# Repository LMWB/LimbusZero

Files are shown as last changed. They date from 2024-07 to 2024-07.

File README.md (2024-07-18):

# LimbusZero
Custom Microcontroller Board based on STM32C0-Series

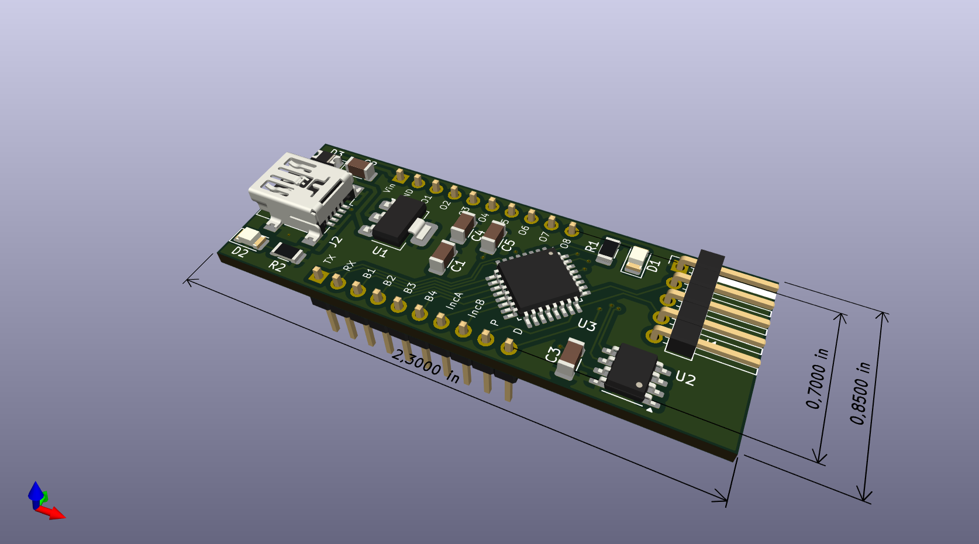
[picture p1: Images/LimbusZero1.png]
front

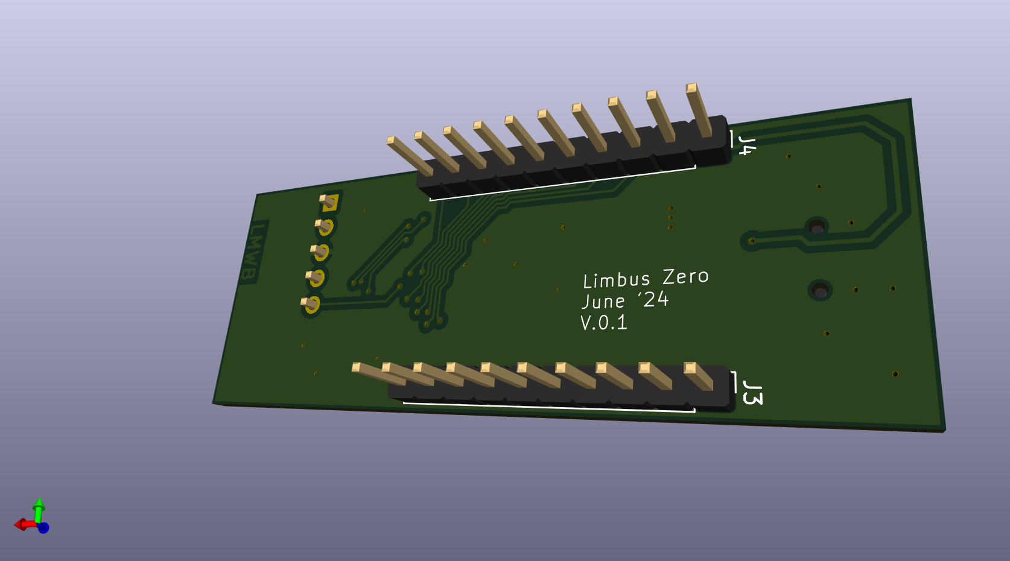
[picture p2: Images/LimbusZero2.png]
back

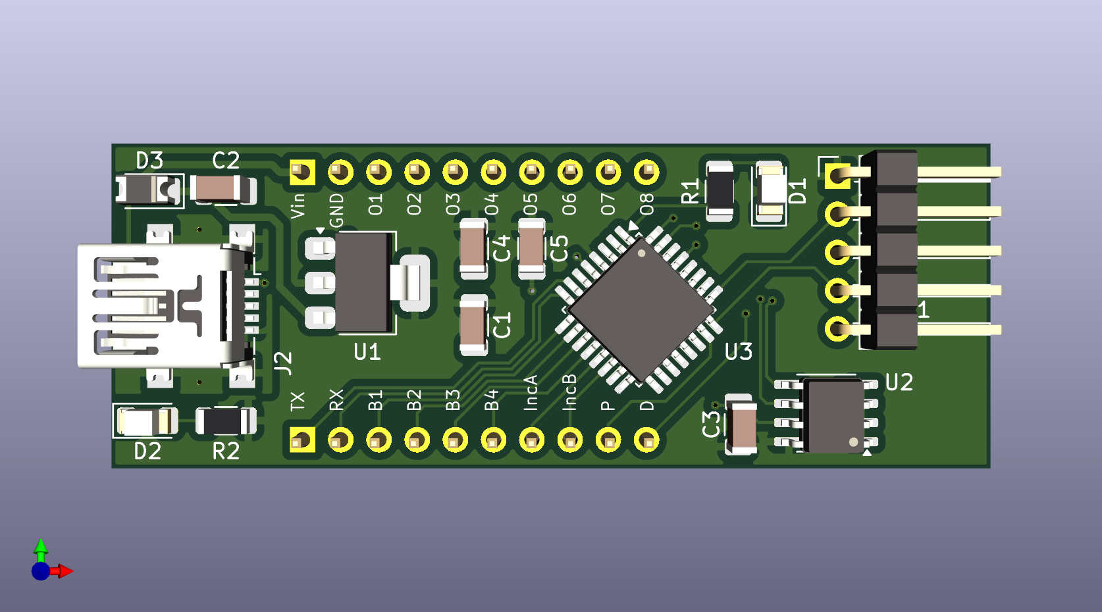
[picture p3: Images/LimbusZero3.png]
top

schematics

# Features
- STM32C031K6T6 Microcontroller
- ST M24C01 I2C EEPROM
- no crystal oscillator since this board uses STM32 build in 48MHz HSI48RC clock generator
    - accuracy needs to be discussed but since software is working fine I guess there will be no dramatic issus 
- Power indicator LED
- USB mini as power supply NO DATA!
- User LED
- 2.54mm Pin Headers that would fit on regular breadbords for rapid prototyping
- debug / programming interface according to STLink that comes with most of STM32 Nucleo Boards

# Firmware
There is quite extensive demo I developed for Emil's Birthday using the [breadbord-IO](https://github.com/LMWB/BreadboardIO) and a [neopixel](https://www.az-delivery.de/products/kopie-von-rgb-led-ring-ws2812-mit-12-rgb-leds-5v-fuer-arduino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) ring in the software sub folder. It's written in C and uses the STM32-HAL and STM32-cubeIDE. Look closely, main-loop is empty since all features and peripherals are controlled by interrupts so the user section `while(1){}` remains untouched. 

# Todo
- add user button

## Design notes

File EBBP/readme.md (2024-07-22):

# Emil's Birthday Breadboard Project 🤓 🛰️ :electron:
25 Tolle Experimente mit Strom, Bits und Bytes

https://github.com/LMWB/LimbusZero

## Inhalt
- Breadboard
- Netzteil
- Adapter für Spannungsversorgung (schwarz)
- LED mit Vorwiderstand
- BreadboardIO Platine (blau)
- LimbusZero Microcontroller Platine (lila)
- RGB-LED Ring
- RGB-LED Streifen
- Ein Satz Jumper Kabel verschiedener Länge
 
# Teil I: Spannungsversorgung
Schnapp dir das Breadbord (weisses plastik Brett mit vielen Löchern) und steck die Adapter Platine für das Netzteil drauf. Jetzt noch das dicke schwarze Netzteil an die Steckdose steck und mit der Adapterplatine verbinden, einschalten und schon hast du Saft auf der Mühle.

Bitte schau genau, dass die Polarität stimmt. Plus ist Rot und Minus ist blau.

# Teil II: Mein erstes Bauteil die LED
Jetzt kommt das erste elektronische Bauteil für dein erstes Experiment. Gemeint ist die kleine LED mit Widerstand angelötet. Schau was passiert wenn du sie auf das Powerrail steckst. Also ein Beinchen auf den Roten und das andere auf den Blauen Kontakt.
Passiert nix? Dann vertausche die Beinchen. 

Die Adapterplatine hat zwei kleine gelbe Brücken. Sie entscheiden ob 5V oder 3.3V Spannung auf dem Powerrail links bzw. recht anliegen. Versuch mal die Brücke abzuziehen und auf eine ander Position zu stecken.

Gibt es einen Unterschied? ______________________________

Woran könnte es liegen dass die LED leuchtet aber vertauscht man die Beinchen leutet sie nicht? ____________________________

# Teil III: Das breadboardIO Extension Board
{sprich: bräd bord Ei Oh und steht für Brotbrett Input Output}

Für die weiteren Versuche brauchst du die blaue Platinen mit den Knöpfen drauf.

## Aufstecken
Die Spannungsversorgung sollte jetzt auf beiden Sietenn auf 3V3 eingestellt sein.
Beim ersten mal aufstecken kann es sehr schwergängig sein. Bitte sei vorsichtig. Die goldenen Metallstifte (Pins) dürfen auf keinen Fall verbiegen.
Am Besten du holst dir Hilfe von einem Erwachsenen. 

Der doppelreihiger 3-fach Pin-Header muss auf das Power Rail. Wenn die grüne LED am breabboardIO leuchtet hast du es richtig gemacht, die Polarität stimmt!

## LED's
Die Spannungsversorgung sollte jetzt auf beiden Sietenn auf 3V3 eingestellt sein.
Verwende eines der beiligenden Jumper-Kabel und stecke das eine Ende auf das Power Rail ➕ Potential (rot). Mit dem anderen Ende kanst du der Reihe nach 
die mittleren 8 Pins abgreifen (leider habe ich vergessen diese zu beschriften J3 heisst die Stiftleiste).
Es sollte jeweils eine LED leuchten.

Welche Farben gibt es und wieviele? ____________________

Versuche es nocheinmal aber diesmal die Spannungsversorgung mit 5V eingestellt. kannst du einen Unterschied feststellen? _____________________

## Taster
Die Spannungsversorgung darf auf 3V3 oder 5V eingestellt sein.
Das bradbordIO hat 4 kleine schwarze Taster. Die Taster sind auf der Platine auf die oberen 4 Pins geführt, gekennzeichnet mit B1 bis B4 an der Stiftleiste J2.
Schnapp dir noch einmal das Jumper-Kabel von eben. Diesmal steckst du das eine Ende auf den Pin B1 und das andere auf eine beliebige LED. Dasnn drücke den Taster 1, der ganz oberer 👌

Probiere auch gern alle andere Taster. Es gibt noch einen fünften, der ist aber versteckt. Kannst du ihn finden?

Der fünfte Taster ist __________________________________________________

## Poti
Korrekterweise heisst das weisse flache Ding ganz oben Potenziometer aber das ist ein 💩-Wort, Poti klingt viel cooler.
Ein Poti ist ein drehbarer Spannungsteiler ... ach egal du wirst schon sehen was es macht.
Die Spannungsversorgung darf auf 3V3 oder 5V eingestellt sein. Wieder kommt das Jumper-Kabel zum Einsatz.
Das eine Ende steckst du auf den Pin mit der Beschriftung Poit (jaaa ich weiss ich habe mich verschrieben 🙈) das andere darf auf eine beliebige LED.
Jetzt brauchst du einen kleinen Schraubendreher und drehst das Poti hin und her.

Was passiert mit der LED? _________________________

Versuche gern auch eine andere Farbe. Fällt dir was auf? __________________________

Stell die Spannungsversorgung nun auf eine ander Position. Was passiert jetzt? ________________________

## Puls Drehgeber
Ganz unten auf der blauen Platine ist noch ein Drehnuppsi. Und wieder, du ahnst es, brauchen wir ein Jumper Kabel. Das steckst du mit der einen Seite .... *schon wieder auf eine LED voll langweilig* ja genau aber warts ab!

Das andere Ende steckst du bitte auf den dritten Pin von unten, also der vor-vor-letzte. Jetzt am Nuppsi drehen und ganz genau beobachten was passiert ___________________________________________

# Teil IV: LimbusZero Micrcontroller Board
Für die nun anstehende Versuchsreihe, brauchst du das BreadboardIO und die lilane Controller Platine. Das LimbusZero-Board ist dein neuer mini Computer 💻, ein so genannter Microcontroller.
Diese kleinen, cleveren, elektronischen Bauteile sind heutzutage fast überall verbaut. Man kann lustige Sachen mit ihnen machen wie du gleich fstestellen wirst.

Aber fangen wir von Vorne an. Zu ersteinmal benötigt der mini Cumputer Säääääft 😄 

## Spannungsversorgung
Platziere das LimbusZero Board irgendwo mittig auf dem Breadbord. Die Adapterplatine ist sicher noch angesteckt. Das linke Power-Rail bekommt 5V. Das rechte Power-Rail, auf dem das BreadbordIO steckt, bekommt 3V3. Jetzt verbindest du + (rot) mit dem Vin-Pin und - (blau) mit GND-Pin. Am besten du verwendest hier auch ein rotes und ein blaues Jumper Kabel. Hast du alles richtig gemacht leuchte eine grüne LED und der Herzschlag beginnt :heart_eyes: :heartbeat: 

## Heartbeet
{sprich Hart Biet es bedeutet Herzschlag}

Der LimbusZero hat eine rote LED und einen Heartbeat einprogrammiert, damit du weisst dass er läuft 🏃 auch wenn noch nix angeschlossen ist.

## Betriebsmodi
Der LimbusZero hat 6 Betriebsmodi. Lass sie uns herausfinde. Doch zuerst muessen wir noch ein paar Strippen ziehen. 
- Verbinde den Taster 1 mit dem B1-Pin.
- Verbinde das Poti mit dem P-Pin
- Verbinde den vor-vor-letzten Pin mit dem IncA-Pin
- Verbinde den vor-letzten Pin mit dem IncB-Pin

- Verbind alle LED-Pins mit den 01 bis 09-Pins
- bitte in korrekter Reihenfolge
- LED1 -> 01
- LED2 -> 02
- ...
- LED8 -> 08
Puh das war anstrengend. Aber die Mühe hat sich gelohnt. Jetzt können wir (fast) alles teste. Es sollte jetzt so ungefähr so bei dir aussehen.

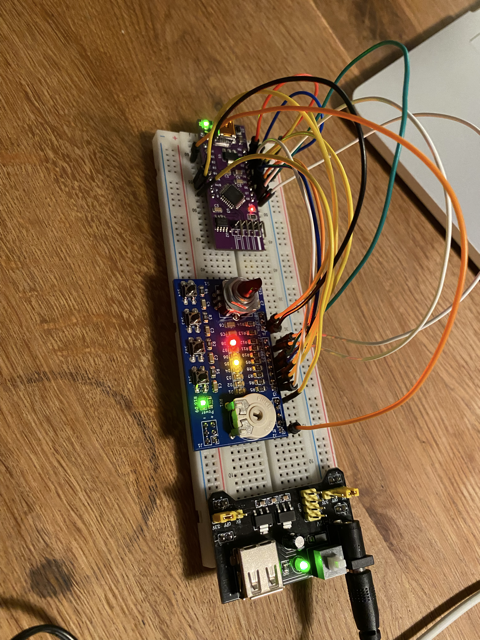
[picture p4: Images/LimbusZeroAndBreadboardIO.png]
Breadboard mit Limbus und BreadbordIO


Die 6 Modie heissen:
- eINCREMENT
- eGAUGE
- eKNIGHTRIDER
- eSNAKE
- eLASTBLINK
- eNEOPIXEL

Wenn du jetzt den Taster 1 drückst wechselt der LimbusZero seine Betriebsmodi. Jeder Modus hat ein spannendes Feature dass du entweder mit dem Poti oder mit dem Drehnuppsi einstellen kannst.

### Modus: Incremet
Mit dem Drehnuppsi kannst du binär von 0 bis 255 zählen. 

### Modus: Gauge (Tachometer)
Schraubendrehe und Poti lassen die LEDs tanzen

### Modus: Knightrider
Kein Kommentar, wir alle kennen Kit! Aber der Drehnuppsi hat bstimmt auch was damit zu tun :sunglasses:

### Modus: Snake
Siehe Knightrider.

### Modus: Lastblink
Das letzte Muster der Schneckenspuhr wechselt ins negative hin und her.

### Modus: NeoPixel
Dafür brauchen wir ein extra Kapitel.

## RGB LED 
RGB steht für Rot, Grpn, Blau. Schau dir den Ring einmal genu an. Es sind 12 LED verlötet und jede dieser LEDs hat drei Farben die wir einzeln ansteuern koenne. Das coole dabei ist, man kann die Farben auch mischen und kann so jede Farbe der Welt selber zusammenbasteln.

Um mit der Zaubere starten zu können, müssen wir ein letzten Mal Kabel ziehen aber vorher Spannung ausschalten bitte!

- Verbinde den Taster 2 mit dem B2-Pin
- Verbinde den Taster 3 mit dem B3-Pin
- Verbinde den Taster 4 mit dem B4-Pin

Ausserdem muss natürlich der LED Ring noch angestöpselt werden. Der Ring hat drei Kabel angelötet. Rot und Blau muss auf das Powerrail (ist egal ob 5V Seite oder 3.3V Seite). Das gelbe Kabel ist die Datenleitung und die muss auf den LimbusZero D-Pin.

Dann die Spannung wieder einschalten und 5x auf den Taster 1 drücken (damit navigieren wir in den Modus 6).
Hast du alles richtig verkabelt sollte der LED-Ring in einer der RGB-Farben leuchten. Mit den Taster 2,3 und 4 kannst du die Farbe ändern und mit dem Drehnubbsi kannst du die Helligkeit der gerade angewählten Farbe anpassen.
Wenn du zum Beispiel Rot ausgewaehlt hast und nochmal auf den Rot-Knopf drückst, erhältst du das Mischergebnis aus alles drei Farben!
Versuch mal Gelb herzustellen!

Gelb mischt man mit der Einstellung ____________________________________________

## RGB LED Streifen
siehe RGB LED

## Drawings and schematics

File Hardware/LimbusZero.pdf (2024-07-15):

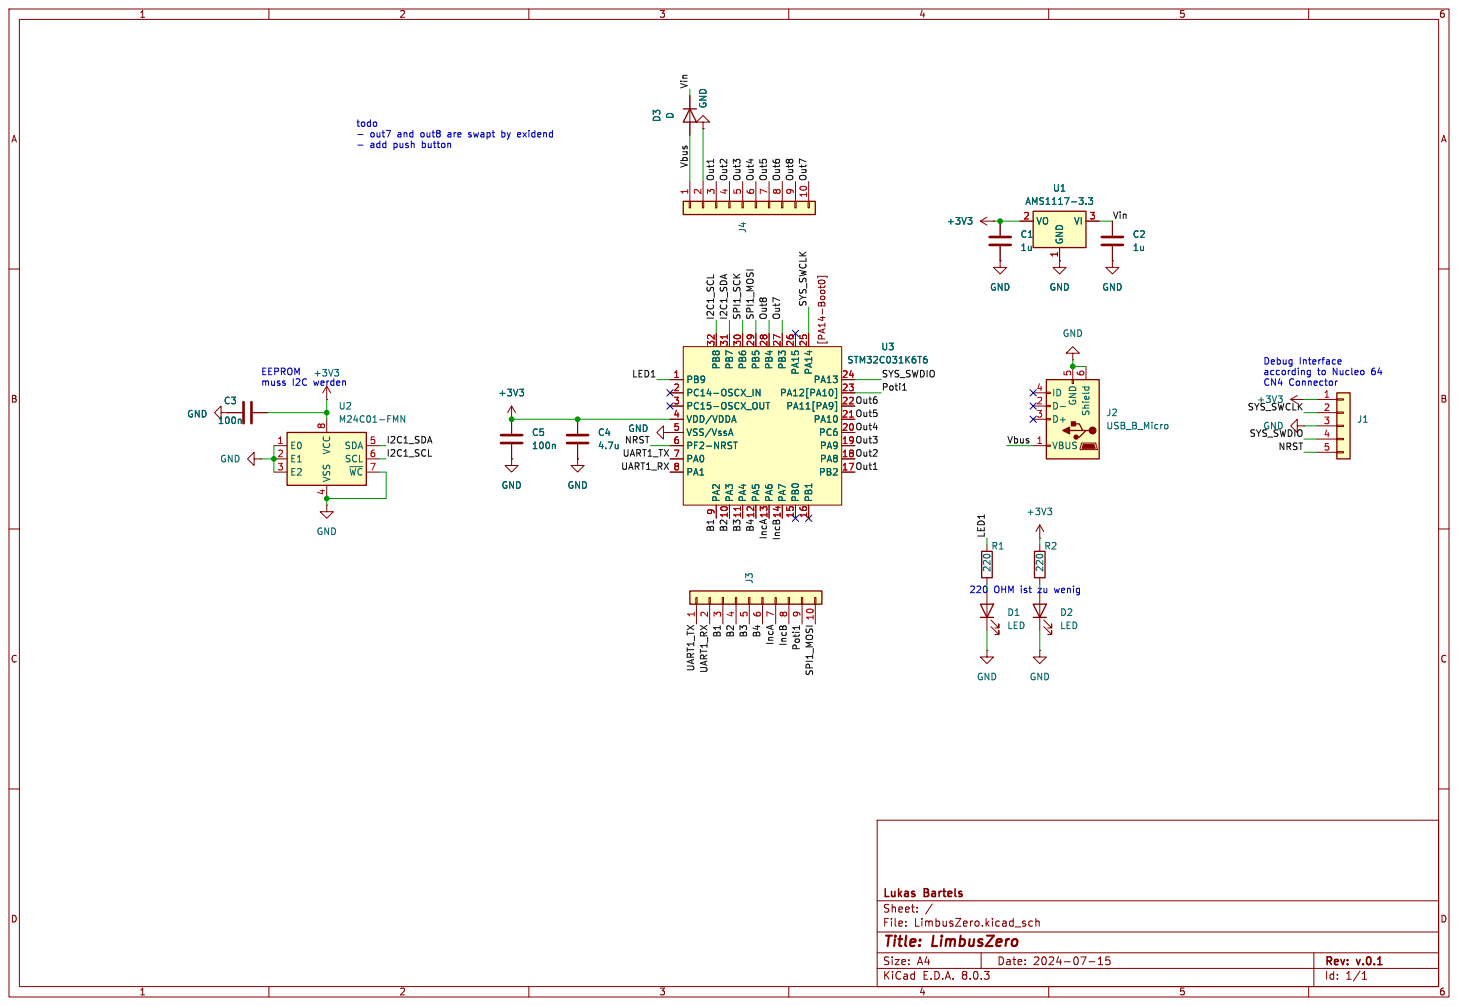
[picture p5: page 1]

220 OHM ist zu wenig GND D3D

todo
- out7 and out8 are swapt by exidend

4 SDA 5 SCL 6 ~{WC}7 VCC

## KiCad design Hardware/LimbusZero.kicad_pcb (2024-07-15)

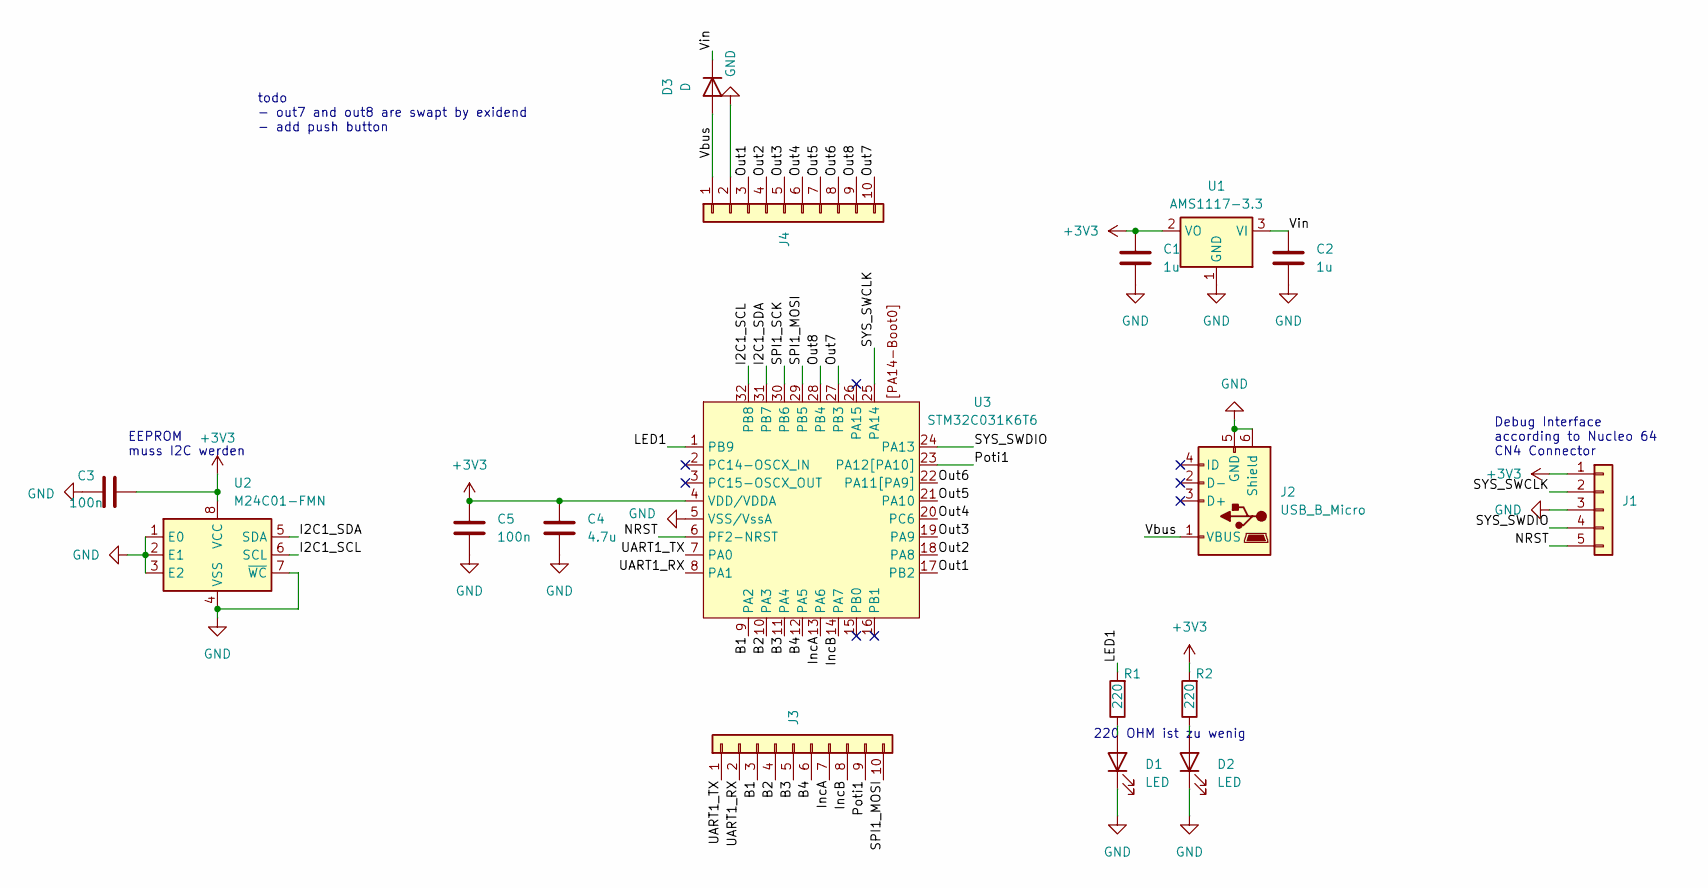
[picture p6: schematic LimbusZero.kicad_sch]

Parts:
C1, C2: 1u; C_1206_3216Metric
C3, C5: 100n; C_1206_3216Metric
C4: 4.7u; C_1206_3216Metric
D1, D2: LED; LED_1206_3216Metric
D3: D; D_1206_3216Metric
J1: Conn_01x05; PinHeader_1x05_P2.54mm_Horizontal
J2: USB_B_Micro; USB_Mini-B_Lumberg_2486_01_Horizontal
J3, J4: Conn_01x10; PinHeader_1x10_P2.54mm_Vertical
R1, R2: 220; R_1206_3216Metric
U1: AMS1117-3.3; SOT-223-3_TabPin2
U2: M24C01-FMN; SOIC-8_3.9x4.9mm_P1.27mm
U3: STM32C031K6T6; LQFP-32_7x7mm_P0.8mm

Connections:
+3V3: C1.1, C3.2, C4.1, C5.1, J1.1, R2.2, U1.2 (VO), U2.8 (VCC), U3.4 (VDD/VDDA)
/B1: J3.3, U3.9 (PA2)
/B2: J3.4, U3.10 (PA3)
/B3: J3.5, U3.11 (PA4)
/B4: J3.6, U3.12 (PA5)
/I2C1_SCL: U2.6 (SCL), U3.32 (PB8)
/I2C1_SDA: U2.5 (SDA), U3.31 (PB7)
/IncA: J3.7, U3.13 (PA6)
/IncB: J3.8, U3.14 (PA7)
/LED1: R1.2, U3.1 (PB9)
/NRST: J1.5, U3.6 (PF2-NRST)
/Out1: J4.3, U3.17 (PB2)
/Out2: J4.4, U3.18 (PA8)
/Out3: J4.5, U3.19 (PA9)
/Out4: J4.6, U3.20 (PC6)
/Out5: J4.7, U3.21 (PA10)
/Out6: J4.8, U3.22 (PA11[PA9])
/Out7: J4.10, U3.27 (PB3)
/Out8: J4.9, U3.28 (PB4)
/Poti1: J3.9, U3.23 (PA12[PA10])
/SPI1_MOSI: J3.10, U3.29 (PB5)
/SPI1_SCK: U3.30 (PB6)
/SYS_SWCLK: J1.2, U3.25 (PA14)
/SYS_SWDIO: J1.4, U3.24 (PA13)
/UART1_RX: J3.2, U3.8 (PA1)
/UART1_TX: J3.1, U3.7 (PA0)
/Vbus: D3.2 (A), J2.1 (VBUS), J4.1
/Vin: C2.1, D3.1 (K), U1.3 (VI)
GND: C1.2, C2.2, C3.1, C4.2, C5.2, D1.1 (K), D2.1 (K), J1.3, J2.5 (GND), J2.6 (Shield), J4.2, U1.1 (GND), U2.1 (E0), U2.2 (E1), U2.3 (E2), U2.4 (VSS), U2.7 (~WC), U3.5 (VSS/VssA)
unnamed: D1.2 (A), R1.1
unnamed: D2.2 (A), R2.1

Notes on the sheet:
EEPROM muss I2C werden
220 OHM ist zu wenig
Debug Interface according to Nucleo 64 CN4 Connector
todo - out7 and out8 are swapt by exidend - add push button

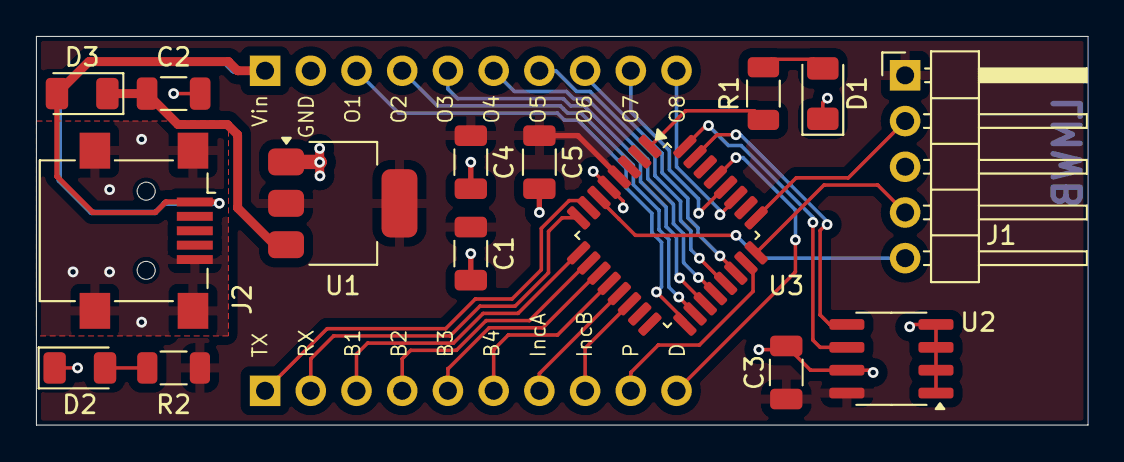
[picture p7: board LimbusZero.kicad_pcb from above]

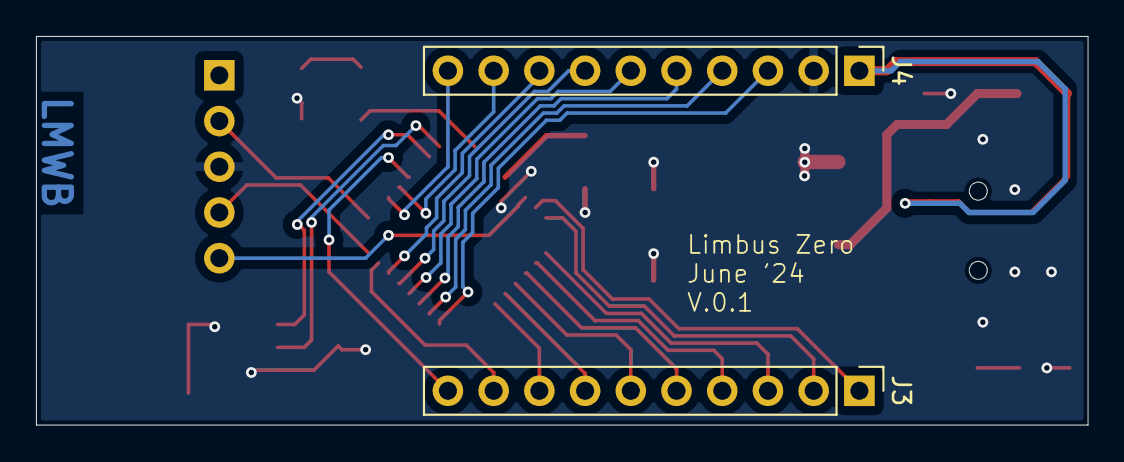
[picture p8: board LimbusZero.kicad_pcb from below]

Board: 2 copper layers, 58.4 x 21.6 mm, 17 parts (2 on the bottom side), 30 nets.

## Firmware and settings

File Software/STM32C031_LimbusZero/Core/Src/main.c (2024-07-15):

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
/* Includes ------------------------------------------------------------------*/
#include "main.h"
#include "adc.h"
#include "dma.h"
#include "i2c.h"
#include "spi.h"
#include "tim.h"
#include "usart.h"
#include "gpio.h"

/* USER CODE BEGIN Includes */
#include "breadboradIO.h"
#include "weICLED.h"
/* USER CODE END Includes */


/* USER CODE BEGIN PV */
void limbuszero_heartbeat(void);
/* USER CODE END PV */

void SystemClock_Config(void);
void PeriphCommonClock_Config(void);
/**
  * @brief  The application entry point.
  * @retval int
  */
int main(void)
{

  /* MCU Configuration--------------------------------------------------------*/

  /* Reset of all peripherals, Initializes the Flash interface and the Systick. */
  HAL_Init();

  /* Configure the system clock */
  SystemClock_Config();

/* Configure the peripherals common clocks */
  PeriphCommonClock_Config();

  /* Initialize all configured peripherals */
  MX_GPIO_Init();
  MX_DMA_Init();
  MX_SPI1_Init();
  MX_USART1_UART_Init();
  MX_I2C1_Init();
  MX_ADC1_Init();
  MX_TIM17_Init();
  MX_TIM16_Init();
  /* USER CODE BEGIN 2 */

	HAL_Delay(100);

	HAL_TIM_PWM_Start_IT(&htim17, TIM_CHANNEL_1);
	HAL_TIM_Base_Start_IT(&htim16);

	HAL_ADCEx_Calibration_Start(&hadc1);
	HAL_ADC_Start_DMA(&hadc1, g_adc_raw_values, ADC_NO_OF_CHANNELS);

	breadboardIO_init();

	/* run a demo if you like */
	//neopixel_demo();

  /* USER CODE END 2 */

  /* Infinite loop */
  /* USER CODE BEGIN WHILE */
	while (1) {
    /* USER CODE END WHILE */

    /* USER CODE BEGIN 3 */

	}
  /* USER CODE END 3 */
}

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
/* USER CODE BEGIN 4 */

void limbuszero_heartbeat(void){
	static int8_t counter = 0;
	static uint8_t direction = 0; /* 0 => up, else => down */
	/* https://www.mikrocontroller.net/articles/LED-Fading */
//	const uint16_t pwmtable_8D[32] =
//	{
//	    0, 1, 2, 2, 2, 3, 3, 4, 5, 6, 7, 8, 10, 11, 13, 16, 19, 23,
//	    27, 32, 38, 45, 54, 64, 76, 91, 108, 128, 152, 181, 215, 255
//	};

	const uint16_t pwmtable_10[64] =
	{
	    0, 1, 1, 2, 2, 2, 2, 2, 3, 3, 3, 4, 4, 5, 5, 6, 6, 7, 8, 9, 10,
	    11, 12, 13, 15, 17, 19, 21, 23, 26, 29, 32, 36, 40, 44, 49, 55,
	    61, 68, 76, 85, 94, 105, 117, 131, 146, 162, 181, 202, 225, 250,
	    279, 311, 346, 386, 430, 479, 534, 595, 663, 739, 824, 918, 1023
	};

	__HAL_TIM_SET_COMPARE(&htim17, TIM_CHANNEL_1, pwmtable_10[counter]);

	/* counting up */
	if (direction == 0) {
		counter++;
		if (counter >= 64-1) {
			direction = 1;
		}
	/* counting down */
	} else {
		counter--;
		if (counter <= 0) {
			direction = 0;
		}
	}
}

void HAL_GPIO_EXTI_Falling_Callback(uint16_t GPIO_Pin) {
	breadbordIO_button_interrupt_callback(GPIO_Pin);
}

void HAL_ADC_ConvCpltCallback(ADC_HandleTypeDef *hadc) {
	HAL_ADC_Start_DMA(&hadc1, g_adc_raw_values, ADC_NO_OF_CHANNELS);
}

void HAL_TIM_PeriodElapsedCallback(TIM_HandleTypeDef *htim) {
	if (htim->Instance == TIM16) {
		limbuszero_heartbeat();
		breadboardIO_FSM();
	}
}

void HAL_TIM_PWM_PulseFinishedCallback(TIM_HandleTypeDef *htim) {
	__NOP();
}

/* USER CODE END 4 */
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


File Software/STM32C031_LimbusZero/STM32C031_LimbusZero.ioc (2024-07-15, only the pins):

Mcu.UserName=STM32C031K6Tx
PA0.Signal=USART1_TX
PA1.Signal=USART1_RX
PA10.GPIO_Label=Out5
PA10.Signal=GPIO_Output
PA13.Signal=DEBUG_SWDIO
PA14-BOOT0.Signal=DEBUG_SWCLK
PA2.GPIO_Label=B1
PA2.Signal=GPXTI2
PA3.GPIO_Label=B2
PA3.Signal=GPXTI3
PA4.GPIO_Label=B3
PA4.Signal=GPXTI4
PA5.GPIO_Label=B4
PA5.Signal=GPXTI5
PA6.GPIO_Label=IncA
PA6.Signal=GPXTI6
PA7.GPIO_Label=IncB
PA7.Signal=GPIO_Input
PA8.GPIO_Label=Out2
PA8.Signal=GPIO_Output
PA9.GPIO_Label=Out3
PA9.Signal=GPIO_Output
PB2.GPIO_Label=Out1
PB2.Signal=GPIO_Output
PB3.GPIO_Label=Out8
PB3.Signal=GPIO_Output
PB4.GPIO_Label=Out7
PB4.Signal=GPIO_Output
PB5.Signal=SPI1_MOSI
PB6.Signal=SPI1_SCK
PB7.Signal=I2C1_SDA
PB8.Signal=I2C1_SCL
PB9.GPIO_Label=Onboard_LED
PB9.Signal=S_TIM17_CH1
PC6.GPIO_Label=Out4
PC6.Signal=GPIO_Output

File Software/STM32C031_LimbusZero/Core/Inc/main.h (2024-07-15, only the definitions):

#define ADC_NO_OF_CHANNELS 4
#define Onboard_LED_Pin GPIO_PIN_9
#define Onboard_LED_GPIO_Port GPIOB
#define B1_Pin GPIO_PIN_2
#define B1_GPIO_Port GPIOA
#define B1_EXTI_IRQn EXTI2_3_IRQn
#define B2_Pin GPIO_PIN_3
#define B2_GPIO_Port GPIOA
#define B2_EXTI_IRQn EXTI2_3_IRQn
#define B3_Pin GPIO_PIN_4
#define B3_GPIO_Port GPIOA
#define B3_EXTI_IRQn EXTI4_15_IRQn
#define B4_Pin GPIO_PIN_5
#define B4_GPIO_Port GPIOA
#define B4_EXTI_IRQn EXTI4_15_IRQn
#define IncA_Pin GPIO_PIN_6
#define IncA_GPIO_Port GPIOA
#define IncA_EXTI_IRQn EXTI4_15_IRQn
#define IncB_Pin GPIO_PIN_7
#define IncB_GPIO_Port GPIOA
#define Out1_Pin GPIO_PIN_2
#define Out1_GPIO_Port GPIOB
#define Out2_Pin GPIO_PIN_8
#define Out2_GPIO_Port GPIOA
#define Out3_Pin GPIO_PIN_9
#define Out3_GPIO_Port GPIOA
#define Out4_Pin GPIO_PIN_6
#define Out4_GPIO_Port GPIOC
#define Out5_Pin GPIO_PIN_10
#define Out5_GPIO_Port GPIOA
#define Out6_Pin GPIO_PIN_11
#define Out6_GPIO_Port GPIOA
#define Poti1_Pin GPIO_PIN_12
#define Poti1_GPIO_Port GPIOA
#define Out8_Pin GPIO_PIN_3
#define Out8_GPIO_Port GPIOB
#define Out7_Pin GPIO_PIN_4
#define Out7_GPIO_Port GPIOB

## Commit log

2024-07-15 pimp readme add schematics and sub folders
2024-07-15 added software and hardware sources
    [LimbusZero-B_Cu.gbl, LimbusZero-B_Mask.gbs, LimbusZero-B_Paste.gbp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]
2025-06-02 backup kicad files

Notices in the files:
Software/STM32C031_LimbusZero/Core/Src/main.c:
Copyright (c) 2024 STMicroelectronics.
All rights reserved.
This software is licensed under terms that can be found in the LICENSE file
